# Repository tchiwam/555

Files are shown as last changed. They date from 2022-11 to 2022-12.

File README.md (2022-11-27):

# 555
555 Xmas piano card, led blinker, noise maker ... 

Just solder only 1 of the 5 possible resistors per switch, depending how good you are, go all the way to 0201...

The current BOM is Digikey centric, but should be available from anywhere.

I will add multiple languages greetings if you send them to me.  

The license is Let me know you are making them :)
Thanks for the donations ! You are welcome ;)



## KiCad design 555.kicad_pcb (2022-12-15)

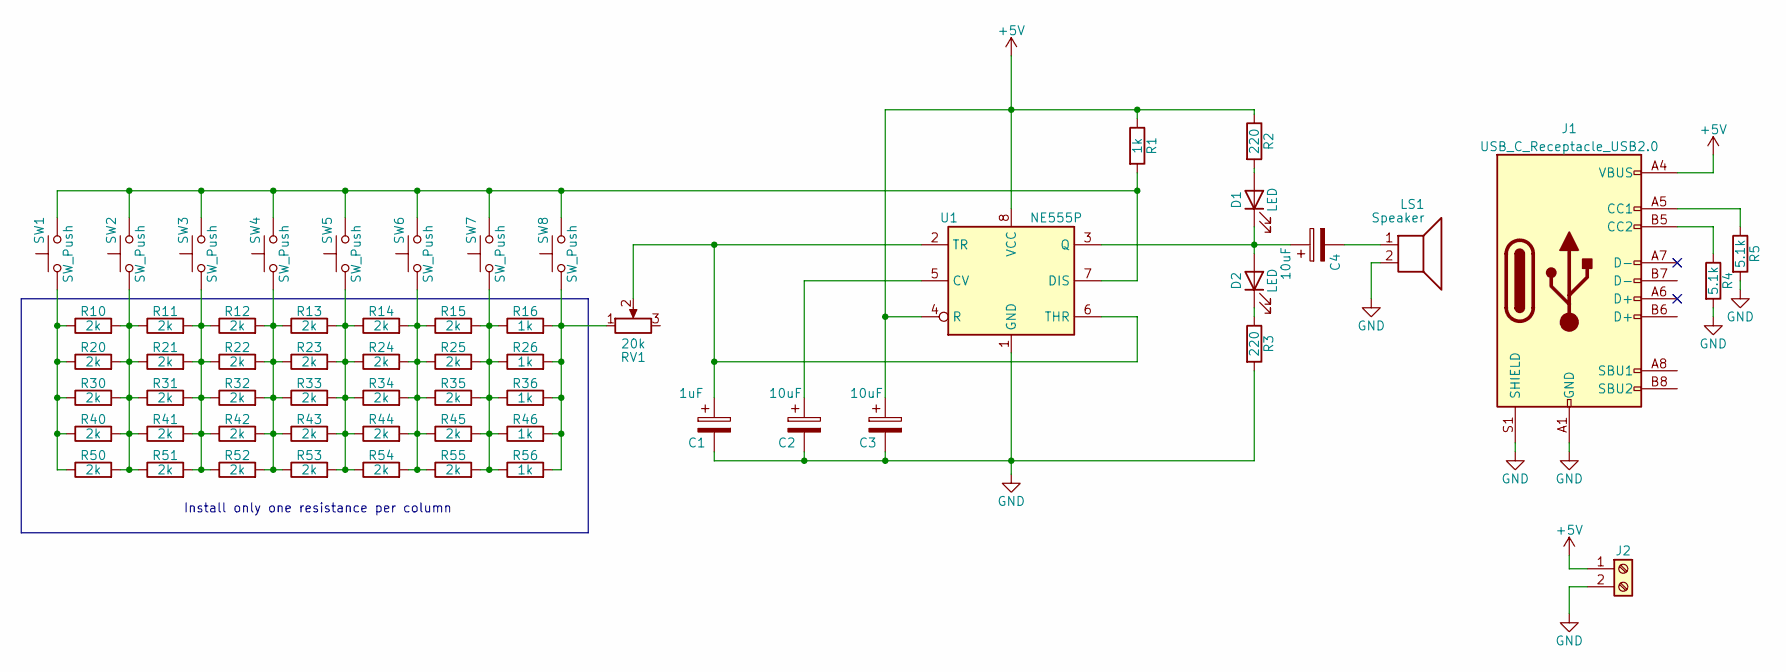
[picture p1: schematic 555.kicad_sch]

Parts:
C1: 1uF; CP_Radial_D5.0mm_P2.00mm; Manufacturer part number 732-8625-1-ND
C2, C3, C4: 10uF; CP_Radial_D5.0mm_P2.00mm; Manufacturer part number 732-8625-1-ND
D1: LED; LED_D5.0mm; Manufacturer part number 160-1853-ND
D2: LED; LED_D5.0mm; Manufacturer part number 160-1852-ND
J1: USB_C_Receptacle_USB2.0; USB_C_Receptacle_GCT_USB4085
J2: Screw_Terminal_01x02; TerminalBlock_Phoenix_PT-1,5-2-5.0-H_1x02_P5.00mm_Horizontal
LS1: Speaker; TerminalBlock_Phoenix_PT-1,5-2-5.0-H_1x02_P5.00mm_Horizontal; Manufacturer part number 458-1124-ND
R1, R16: 1k; R_Axial_DIN0207_L6.3mm_D2.5mm_P10.16mm_Horizontal; Manufacturer part number RNF14FTD1K00CT-ND
R2, R3: 220; R_Axial_DIN0207_L6.3mm_D2.5mm_P10.16mm_Horizontal; Manufacturer part number S220CACT-ND
R4, R5: 5.1k; R_Axial_DIN0207_L6.3mm_D2.5mm_P10.16mm_Horizontal; Manufacturer part number RNF14FTD1K00CT-ND
R10, R11, R12, R13, R14, R15: 2k; R_Axial_DIN0207_L6.3mm_D2.5mm_P10.16mm_Horizontal; Manufacturer part number RNF14FTD2K00CT-ND
R20, R21, R22, R23, R24, R25: 2k; R_1206_3216Metric; Manufacturer part number 738-RMCF1206FG2K00CT-ND
R26: 1k; R_1206_3216Metric; Manufacturer part number RNCP1206FTD1K00CT-ND
R30, R31, R32, R33, R34, R35: 2k; R_0603_1608Metric; Manufacturer part number P2.00KHCT-ND
R36: 1k; R_0603_1608Metric; Manufacturer part number RNCP0603FTD1K00CT-ND
R40, R41, R42, R43, R44, R45: 2k; R_0402_1005Metric; Manufacturer part number 541-2.00KLCT-ND
R46: 1k; R_0402_1005Metric; Manufacturer part number 311-1.0KJRCT-ND
R50, R51, R52, R53, R54, R55: 2k; R_0201_0603Metric; Manufacturer part number P123271CT-ND
R56: 1k; R_0201_0603Metric; Manufacturer part number 311-1KMCT-ND
RV1: 20k; Potentiometer_TT_P0915N; Manufacturer part number 987-1277-ND
SW1, SW2, SW3, SW4, SW5, SW6, SW7, SW8: SW_Push; SW_PUSH_6mm; Manufacturer part number 679-2428-ND
U1: NE555P; DIP-8_W7.62mm; Manufacturer part number 296-NE555P-ND

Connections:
+5V: C3.1, J1.A4 (VBUS), J1.A9 (VBUS), J1.B4 (VBUS), J1.B9 (VBUS), J2.1, R1.1, R2.1, U1.4 (R), U1.8 (VCC)
GND: C1.2, C2.2, C3.2, J1.A1 (GND), J1.A12 (GND), J1.B1 (GND), J1.B12 (GND), J1.S1 (SHIELD), J2.2, LS1.2, R3.2, R4.2, R5.2, U1.1 (GND)
unnamed: C1.1, RV1.2, U1.2 (TR), U1.6 (THR)
unnamed: C2.1, U1.5 (CV)
unnamed: C4.1, D1.1 (K), D2.2 (A), U1.3 (Q)
unnamed: C4.2, LS1.1
unnamed: D1.2 (A), R2.2
unnamed: D2.1 (K), R3.1
unnamed: J1.A5 (CC1), R5.1
unnamed: J1.B5 (CC2), R4.1
unnamed: R1.2, SW1.2, SW2.2, SW3.2, SW4.2, SW5.2, SW6.2, SW7.2, SW8.2, U1.7 (DIS)
unnamed: R10.1, R20.1, R30.1, R40.1, R50.1, SW1.1
unnamed: R10.2, R11.1, R20.2, R21.1, R30.2, R31.1, R40.2, R41.1, R50.2, R51.1, SW2.1
unnamed: R11.2, R12.1, R21.2, R22.1, R31.2, R32.1, R41.2, R42.1, R51.2, R52.1, SW3.1
unnamed: R12.2, R13.1, R22.2, R23.1, R32.2, R33.1, R42.2, R43.1, R52.2, R53.1, SW4.1
unnamed: R13.2, R14.1, R23.2, R24.1, R33.2, R34.1, R43.2, R44.1, R53.2, R54.1, SW5.1
unnamed: R14.2, R15.1, R24.2, R25.1, R34.2, R35.1, R44.2, R45.1, R54.2, R55.1, SW6.1
unnamed: R15.2, R16.1, R25.2, R26.1, R35.2, R36.1, R45.2, R46.1, R55.2, R56.1, SW7.1
unnamed: R16.2, R26.2, R36.2, R46.2, R56.2, RV1.1, SW8.1

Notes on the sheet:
Install only one resistance per column

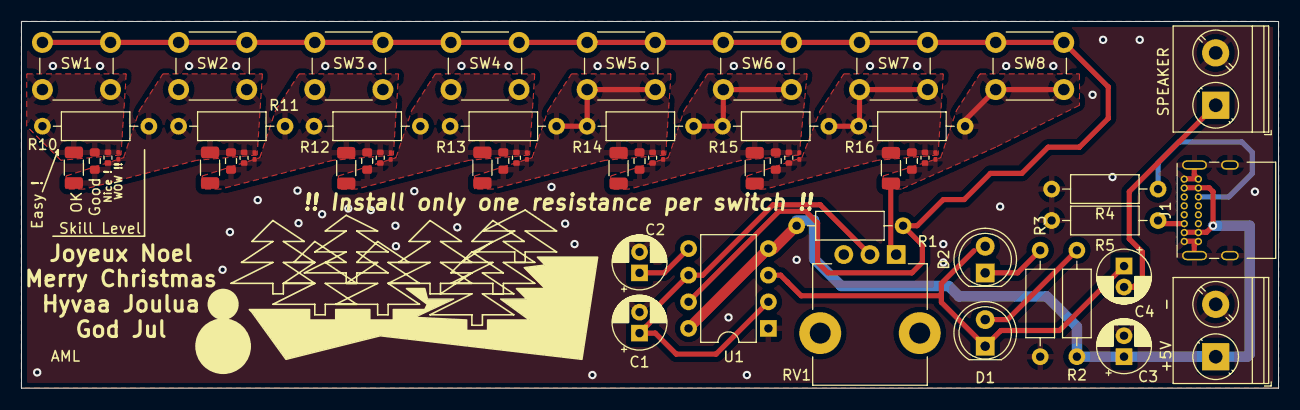
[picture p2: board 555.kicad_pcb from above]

Board: 2 copper layers, 120.0 x 35.0 mm, 59 parts (0 on the bottom side), 19 nets.

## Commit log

2022-11-27 Snow on the branches
    [555.kicad_pcb]
2022-11-30 Simpler, remove the 10k resistor, move the potentiometer to full to play
    [555.kicad_pcb, 555.kicad_sch]
2022-11-30 PCB updated
    [555.kicad_pcb, 555.kicad_sch]
2022-11-30 Prettier sch
    [555.kicad_pcb, 555.kicad_sch]
2022-12-11 USB-C resistor CC
    [555.kicad_sch]
2022-12-14 Art contribution AML
    [555.kicad_pcb]
